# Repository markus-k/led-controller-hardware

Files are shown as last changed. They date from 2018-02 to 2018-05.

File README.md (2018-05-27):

#  12 channel LED controller (hardware files)

This repository contains all KiCad project files for my LED controller project. More information about this project can be found on [Hackaday.io](https://hackaday.io/project/47190-12-channel-led-controller).

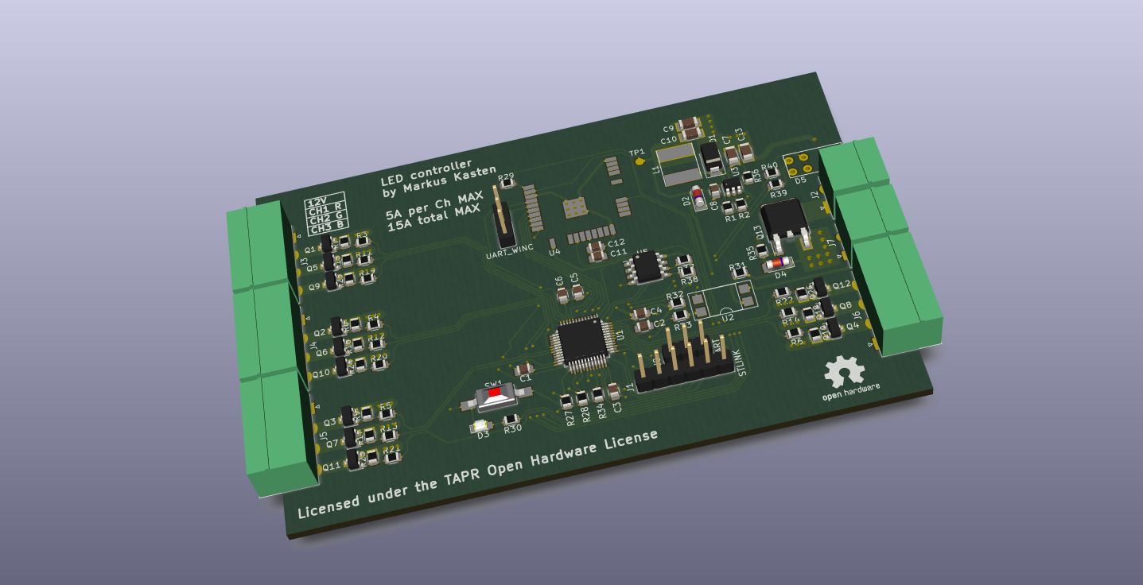
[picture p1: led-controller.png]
Rendered PCB


## Known issues (rev 1.0)

* The 3.3V rail is missing a backup supply (from a big cap for example) and 12-24V presence detection to keep the µC and EEPROM alive for a few more milliseconds after the power went away. It's currently not possible to save the EEPROM on powerdown and thus periodic or event based writes are required, wearing the EEPROM more than needed.
* The 5A/Ch rating does not seem realistic unless smoking hot FETs are okay :)

## License

This project is licensed under the [TAPR Open Hardware License](LICENSE.txt). A copy of the license is included in this repository.

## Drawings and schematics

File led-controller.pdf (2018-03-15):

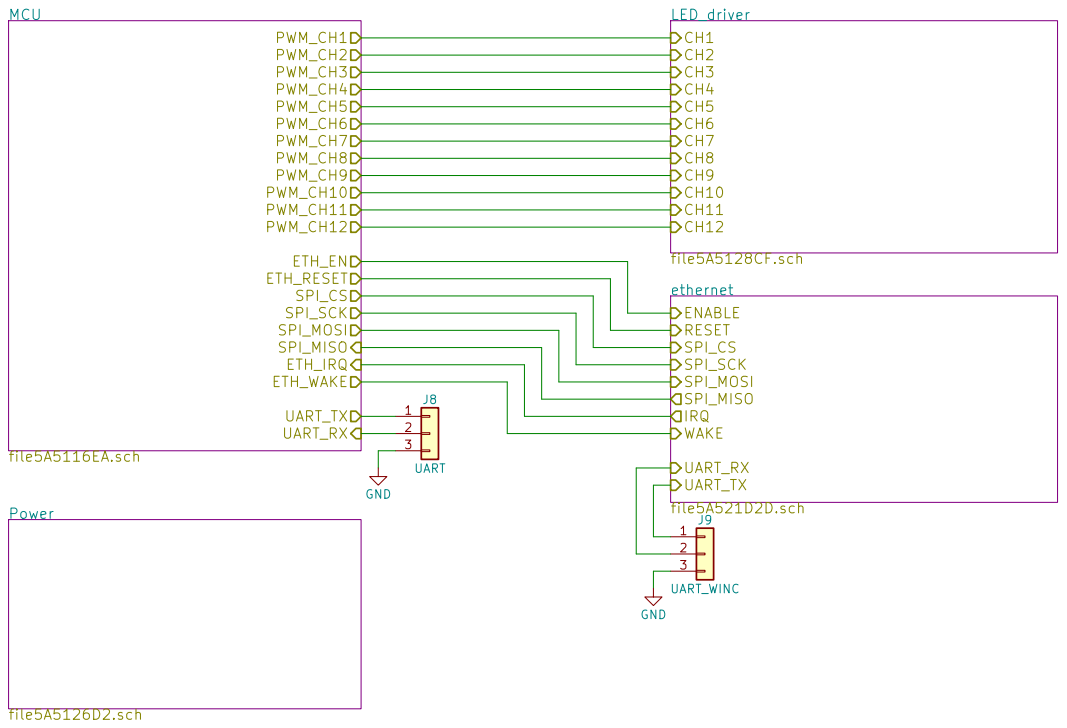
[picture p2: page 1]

Id: 1/5 Title: LED controller File: led-controller.sch Sheet: / Markus Kasten

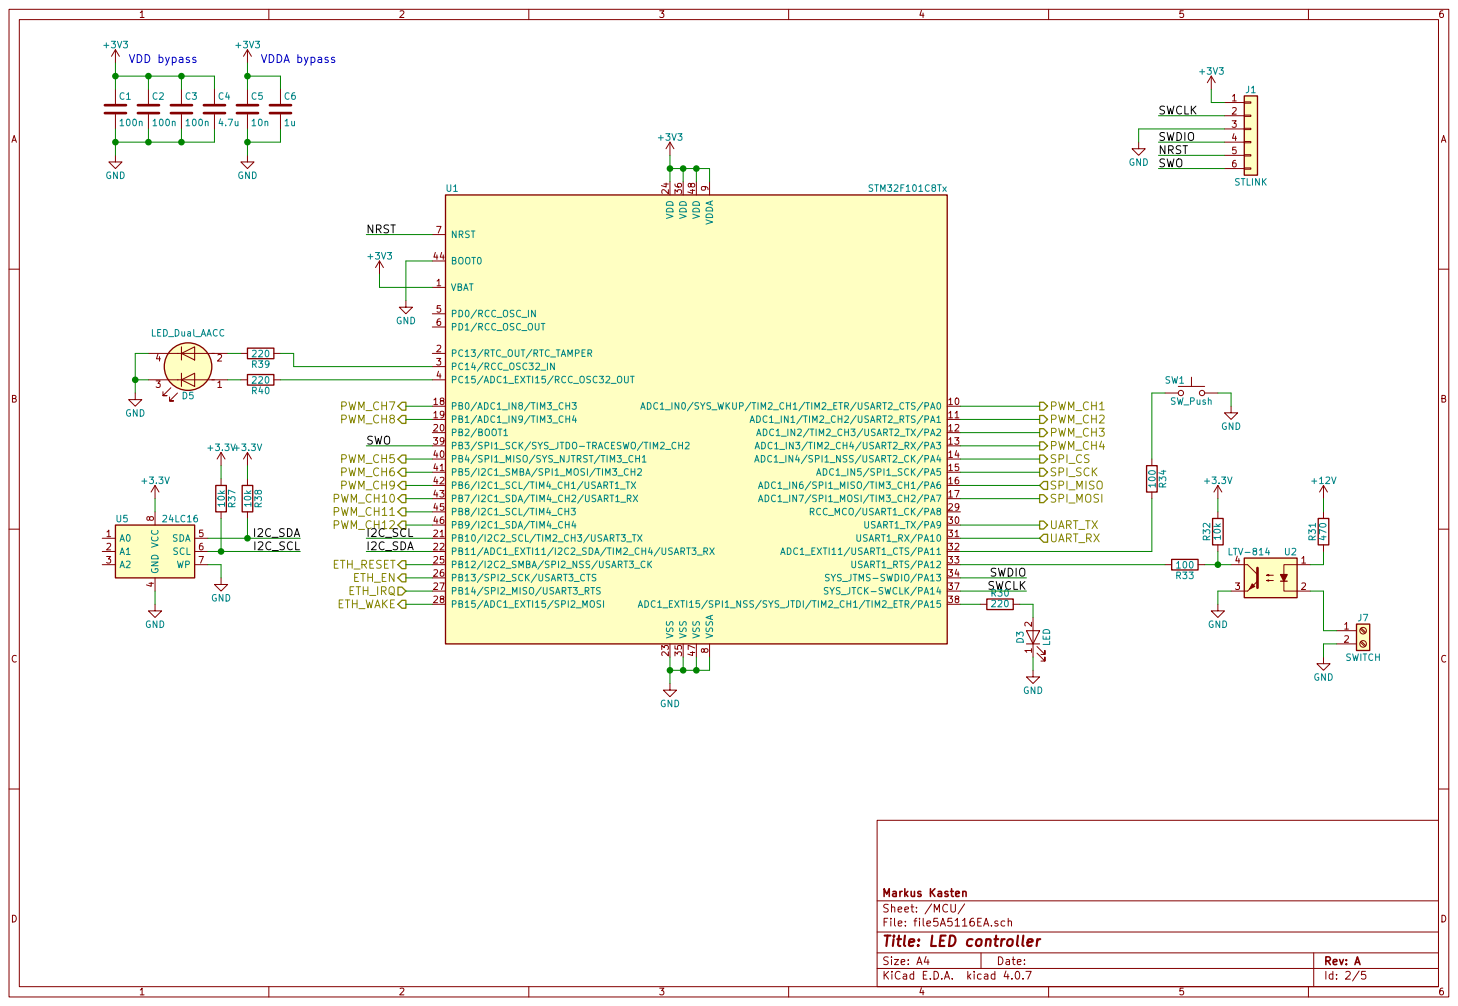
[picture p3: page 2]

9 ADC1_IN0/SYS_WKUP/TIM2_CH1/TIM2_ETR/USART2_CTS/PA0 10 PB2/BOOT1 20 USART1_TX/PA9 30 PB4/SPI1_MISO/SYS_NJTRST/TIM3_CH1 40 ADC1_IN1/TIM2_CH2/USART2_RTS/PA1 11 PB10/I2C2_SCL/TIM2_CH3/USART3_TX 21 USART1_RX/PA10 31 PB5/I2C1_SMBA/SPI1_MOSI/TIM3_CH2 41 ADC1_IN2/TIM2_CH3/USART2_TX/PA2 12 PB11/ADC1_EXTI11/I2C2_SDA/TIM2_CH4/USART3_RX 22 ADC1_EXTI11/USART1_CTS/PA11 32 PB6/I2C1_SCL/TIM4_CH1/USART1_TX 42 ADC1_IN3/TIM2_CH4/USART2_RX/PA3 13 VSS 23 USART1_RTS/PA12 33 PB7/I2C1_SDA/TIM4_CH2/USART1_RX 43 ADC1_IN4/SPI1_NSS/USART2_CK/PA4 14 VDD 24 SYS_JTMS-SWDIO/PA13 34 BOOT0 44 ADC1_IN5/SPI1_SCK/PA5 15 PB12/I2C2_SMBA/SPI2_NSS/USART3_CK 25 VSS 35 PB8/I2C1_SCL/TIM4_CH3 45 ADC1_IN6/SPI1_MISO/TIM3_CH1/PA6 16 PB13/SPI2_SCK/USART3_CTS 26 VDD 36 PB9/I2C1_SDA/TIM4_CH4 46 ADC1_IN7/SPI1_MOSI/TIM3_CH2/PA7 17 PB14/SPI2_MISO/USART3_RTS 27 SYS_JTCK-SWCLK/PA14 37 VSS 47 PB0/ADC1_IN8/TIM3_CH3 18 PB15/ADC1_EXTI15/SPI2_MOSI 28 ADC1_EXTI15/SPI1_NSS/SYS_JTDI/TIM2_CH1/TIM2_ETR/PA15 38 VDD 48 PB1/ADC1_IN9/TIM3_CH4 19 RCC_MCO/USART1_CK/PA8 29 PB3/SPI1_SCK/SYS_JTDO-TRACESWO/TIM2_CH2 39 U1 STM32F101C8Tx GND PWM_CH1

Id: 2/5 Title: LED controller File: file5A5116EA.sch Sheet: /MCU/ Markus Kasten

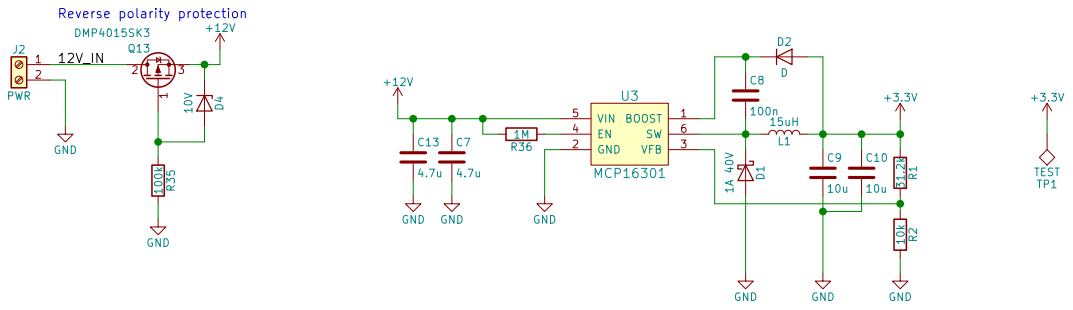
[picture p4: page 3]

Id: 3/5 Title: LED controller File: file5A5126D2.sch Sheet: /Power/ Markus Kasten

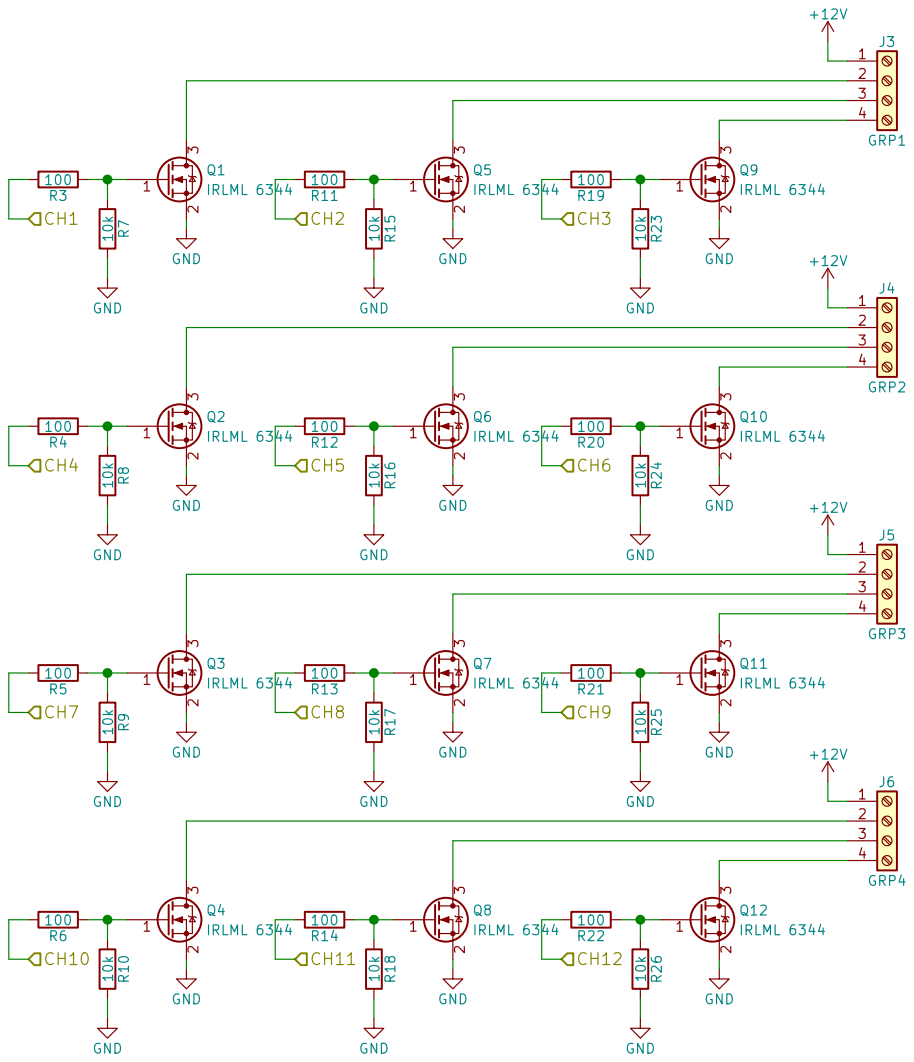
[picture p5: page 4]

Id: 4/5 Title: LED controller File: file5A5128CF.sch Sheet: /LED_driver/ Markus Kasten

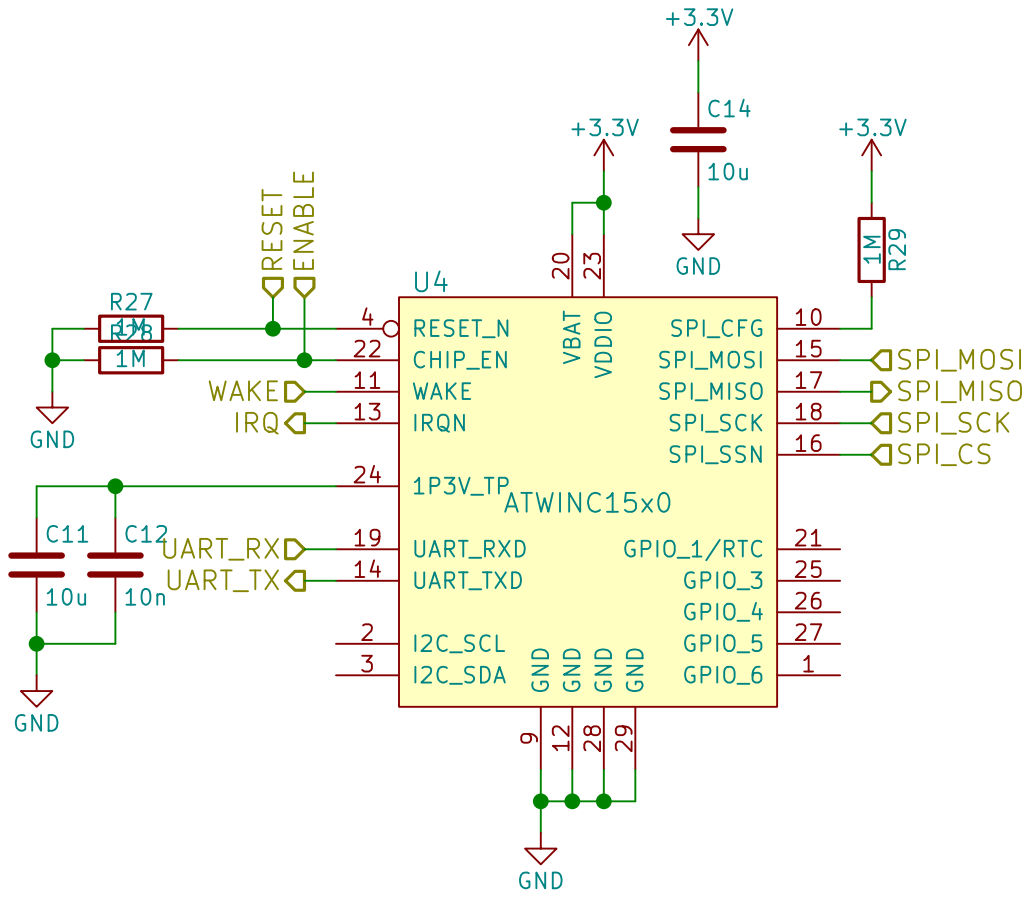
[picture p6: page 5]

9 SPI_CFG 10 VBAT 20 WAKE 11 GPIO_1/RTC 21 GND 12 CHIP_EN 22

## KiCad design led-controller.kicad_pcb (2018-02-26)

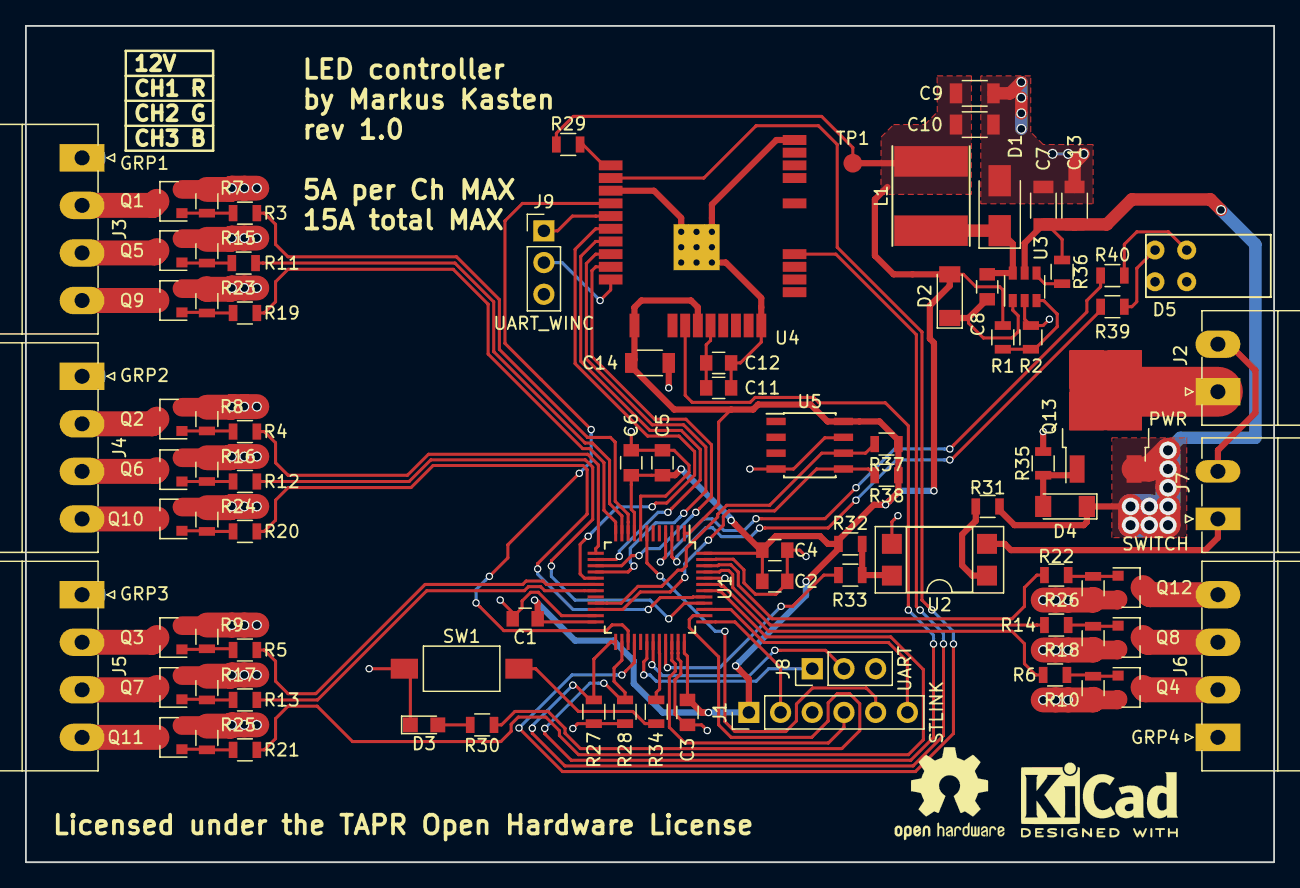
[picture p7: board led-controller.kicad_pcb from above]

Board: 2 copper layers, 100.0 x 67.0 mm, 89 parts (0 on the bottom side), 77 nets.

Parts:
C1, C2, C3, C8: 100n; C_0805
C4: 4.7u; C_0805
C5, C12: 10n; C_0805
C6: 1u; C_0805
C7, C13: 4.7u; C_1206
C9, C10, C14: 10u; C_1206
C11: 10u; C_0805
D1: 1A 40V; D_SMA
D2: D; D_MiniMELF
D3: LED; LED_0805
D4: 10V; D_MiniMELF
D5: LED_Dual_AACC; MEN-1801
J1: STLINK; Pin_Header_Straight_1x06_Pitch2.54mm
J2: PWR; PhoenixContact_MC-G_02x3.81mm_Angled
J3: GRP1; PhoenixContact_MC-G_04x3.81mm_Angled
J4: GRP2; PhoenixContact_MC-G_04x3.81mm_Angled
J5: GRP3; PhoenixContact_MC-G_04x3.81mm_Angled
J6: GRP4; PhoenixContact_MC-G_04x3.81mm_Angled
J7: SWITCH; PhoenixContact_MC-G_02x3.81mm_Angled
J8: UART; Pin_Header_Straight_1x03_Pitch2.54mm
J9: UART_WINC; Pin_Header_Straight_1x03_Pitch2.54mm
L1: 15uH; Inductor_Taiyo-Yuden_NR-60xx_HandSoldering
Q1, Q2, Q3, Q4, Q5, Q6, Q7, Q8, Q9, Q10, Q11, Q12: Q_NMOS_GSD; SOT-23
Q13: DMP4015SK3; TO-252-2
R1: 31.2k; R_0805
R2, R32, R37, R38: 10k; R_0805
R3, R4, R5, R6, R11, R12, R13, R14, R19, R20, R21, R22: 100; R_0805
R7, R8, R9, R10, R15, R16, R17, R18, R23, R24, R25, R26, R35: 100k; R_0805
R27, R28, R29, R36: 1M; R_0805
R30, R31, R33, R34, R39, R40: 1k; R_0805
SW1: SW_Push; SW_SPST_FSMSM
TP1: TEST; Measurement_Point_Round-SMD-Pad_Small
U1: STM32F101C8Tx; LQFP-48_7x7mm_Pitch0.5mm
U2: LTV-814; DIP-4_W7.62mm_SMDSocket_SmallPads
U3: MCP16301; SOT-23-6
U4: ATWINC15x0
U5: 24LC16; SOIC-8_3.9x4.9mm_Pitch1.27mm

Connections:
+3V3: C1.1, C2.1, C3.1, C4.1, C5.1, C6.1, C9.1, C10.1, C14.1, D2.2, J1.1, L1.2, R1.1, R29.1, R32.1, R37.1, R38.1, TP1.1, U1.1, U1.9, U1.24, U1.36, U1.48, U4.20, U4.23, U5.8
+12V: C7.1, C13.1, D4.1, J3.1, J4.1, J5.1, J6.1, Q13.3, R31.1, R36.2, U3.5
/LED_driver/CH1: R3.2, U1.10
/LED_driver/CH2: R11.2, U1.11
/LED_driver/CH3: R19.2, U1.12
/LED_driver/CH4: R4.2, U1.13
/LED_driver/CH5: R12.2, U1.40
/LED_driver/CH6: R20.2, U1.41
/LED_driver/CH7: R5.2, U1.18
/LED_driver/CH8: R13.2, U1.19
/LED_driver/CH9: R21.2, U1.42
/LED_driver/CH10: R6.2, U1.43
/LED_driver/CH11: R14.2, U1.45
/LED_driver/CH12: R22.2, U1.46
/MCU/ETH_IRQ: U1.27, U4.13
/MCU/ETH_RESET: R27.2, U1.25, U4.4
/MCU/ETH_WAKE: U1.28, U4.11
/MCU/I2C_SCL: R37.2, U1.21, U5.6
/MCU/I2C_SDA: R38.2, U1.22, U5.5
/MCU/NRST: J1.5, U1.7
/MCU/SPI_CS: U1.14, U4.16
/MCU/SPI_MISO: U1.16, U4.17
/MCU/SPI_MOSI: U1.17, U4.15
/MCU/SPI_SCK: U1.15, U4.18
/MCU/SWCLK: J1.2, U1.37
/MCU/SWDIO: J1.4, U1.34
/MCU/SWO: J1.6, U1.39
/MCU/UART_RX: J8.2, U1.31
/MCU/UART_TX: J8.1, U1.30
/Power/12V_IN: J2.1, Q13.2
/ethernet/ENABLE: R28.2, U1.26, U4.22
/ethernet/UART_RX: J9.2, U4.19
/ethernet/UART_TX: J9.1, U4.14
GND: C1.2, C2.2, C3.2, C4.2, C5.2, C6.2, C7.2, C9.2, C10.2, C11.2, C12.2, C13.2, C14.2, D1.2, D3.1, D5.3, D5.4, J1.3, J2.2, J7.2, J8.3, J9.3, Q1.2, Q2.2, Q3.2, Q4.2, Q5.2, Q6.2, Q7.2, Q8.2, Q9.2, Q10.2, Q11.2, Q12.2, R2.2, R7.2, R8.2, R9.2, R10.2, R15.2, R16.2, R17.2, R18.2, R23.2, R24.2, R25.2, R26.2, R27.1, R28.1, R35.2, SW1.1, U1.8, U1.23, U1.35, U1.44, U1.47, U2.3, U3.2, U4.9, U4.12, U4.28, U4.29, U5.4, U5.7
unnamed: C8.1, D2.1, U3.1
unnamed: C8.2, D1.1, L1.1, U3.6
unnamed: C11.1, C12.1, U4.24
unnamed: D3.2, R30.2
unnamed: D4.2, Q13.1, R35.1
unnamed: D5.1, R40.2
unnamed: D5.2, R39.2
unnamed: J3.2, Q1.3
unnamed: J3.3, Q5.3
unnamed: J3.4, Q9.3
unnamed: J4.2, Q2.3
unnamed: J4.3, Q6.3
unnamed: J4.4, Q10.3
unnamed: J5.2, Q3.3
unnamed: J5.3, Q7.3
unnamed: J5.4, Q11.3
unnamed: J6.2, Q4.3
unnamed: J6.3, Q8.3
unnamed: J6.4, Q12.3
unnamed: J7.1, U2.2
unnamed: Q1.1, R3.1, R7.1
unnamed: Q2.1, R4.1, R8.1
unnamed: Q3.1, R5.1, R9.1
unnamed: Q4.1, R6.1, R10.1
unnamed: Q5.1, R11.1, R15.1
unnamed: Q6.1, R12.1, R16.1
unnamed: Q7.1, R13.1, R17.1
unnamed: Q8.1, R14.1, R18.1
unnamed: Q9.1, R19.1, R23.1
unnamed: Q10.1, R20.1, R24.1
unnamed: Q11.1, R21.1, R25.1
unnamed: Q12.1, R22.1, R26.1
unnamed: R1.2, R2.1, U3.3
unnamed: R29.2, U4.10
unnamed: R30.1, U1.38
unnamed: R31.2, U2.1
unnamed: R32.2, R33.2, U2.4
unnamed: R33.1, U1.33
unnamed: R34.1, U1.32
unnamed: R34.2, SW1.2
unnamed: R36.1, U3.4
unnamed: R39.1, U1.3
unnamed: R40.1, U1.4

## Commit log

2018-02-09 Initial commit with project files
    [file5A5116EA.sch, file5A5126D2.sch, file5A5128CF.sch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]
2018-02-11 Add UART headers for mcu and winc
    [file5A5116EA.sch, file5A5126D2.sch, file5A5128CF.sch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]
2018-02-20 Add license to silkscreen layer
    [led-controller.kicad_pcb]
2018-02-20 Add rendered board image for README
2018-02-25 Fix wrong pin in ATWINC symbol and add a cap to it's VCC
    [file5A521D2D.sch, led-controller.kicad_pcb]
2018-02-26 Some final silkscreen fixes
    [file5A521D2D.sch, led-controller.kicad_pcb]
2018-03-11 Adjust a couple of component values for consistency with the actual boards
    [file5A5116EA.sch, file5A5128CF.sch]
2018-03-15 Use correct resistor value for opto-coupler
    [file5A5116EA.sch]
2018-03-15 Add PDF of schematic and a photo of the finished PCB
2018-04-13 Use correct values for feedback voltage divider in power supply
    [file5A5126D2.sch]
